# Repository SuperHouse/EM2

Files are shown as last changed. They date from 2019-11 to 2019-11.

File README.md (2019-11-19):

EtherMega2
==========
Copyright 2011-2018 Freetronics Pty Ltd www.freetronics.com.au  

The EtherMega2 is an Arduino-compatible board based on the existing
Arduino Mega2560, but with improvements and updates for features and
ease of use. It also includes on-board Ethernet with PoE (Power-over-
Ethernet) support.

Features:

 * High-efficiency switchmode power supply (input voltage 7-28Vdc)
 * Micro-USB Connector
 * microSD card slot
 * 10/100 Ethernet using the Wiznet W5500 chip
 * Overlay guide where you need it (both top and bottom)
 * D13 pin works for everything

You can learn more at:

  https://www.superhouse.tv/em2

INSTALLATION
------------
The design is saved as an EAGLE project. EAGLE PCB design software is
available from www.cadsoftusa.com free for non-commercial use. To use
this project download it and place the directory containing these files
into the "eagle" directory on your computer. Then open EAGLE and
navigate to the project.

DISTRIBUTION
------------
The specific terms of distribution of this project are governed by the
license referenced below.

LICENSE
-------
This work is licensed under the
Creative Commons Attribution-Share Alike License.  
To view a copy of this license, visit

  http://creativecommons.org/licenses/by-sa/3.0/  
  http://creativecommons.org/licenses/by-sa/3.0/legalcode

or send a letter to

  Creative Commons  
  171 Second Street, Suite 300  
  San Francisco  
  California, 94105  
  USA

The "license" folder within this repository also contains copies of the
licences referenced above.

CREDITS
-------
The EtherMega was designed by Jonathan Oxer (jon@freetronics.com) and
Marc Alexander (marc@freetronics.com) based on previous work by the Arduino
team (www.arduino.cc/playground/Main/People) which includes:

 * Massimo Banzi
 * David Cuartielles
 * Tom Igoe
 * Gianluca Martino
 * David A. Mellis

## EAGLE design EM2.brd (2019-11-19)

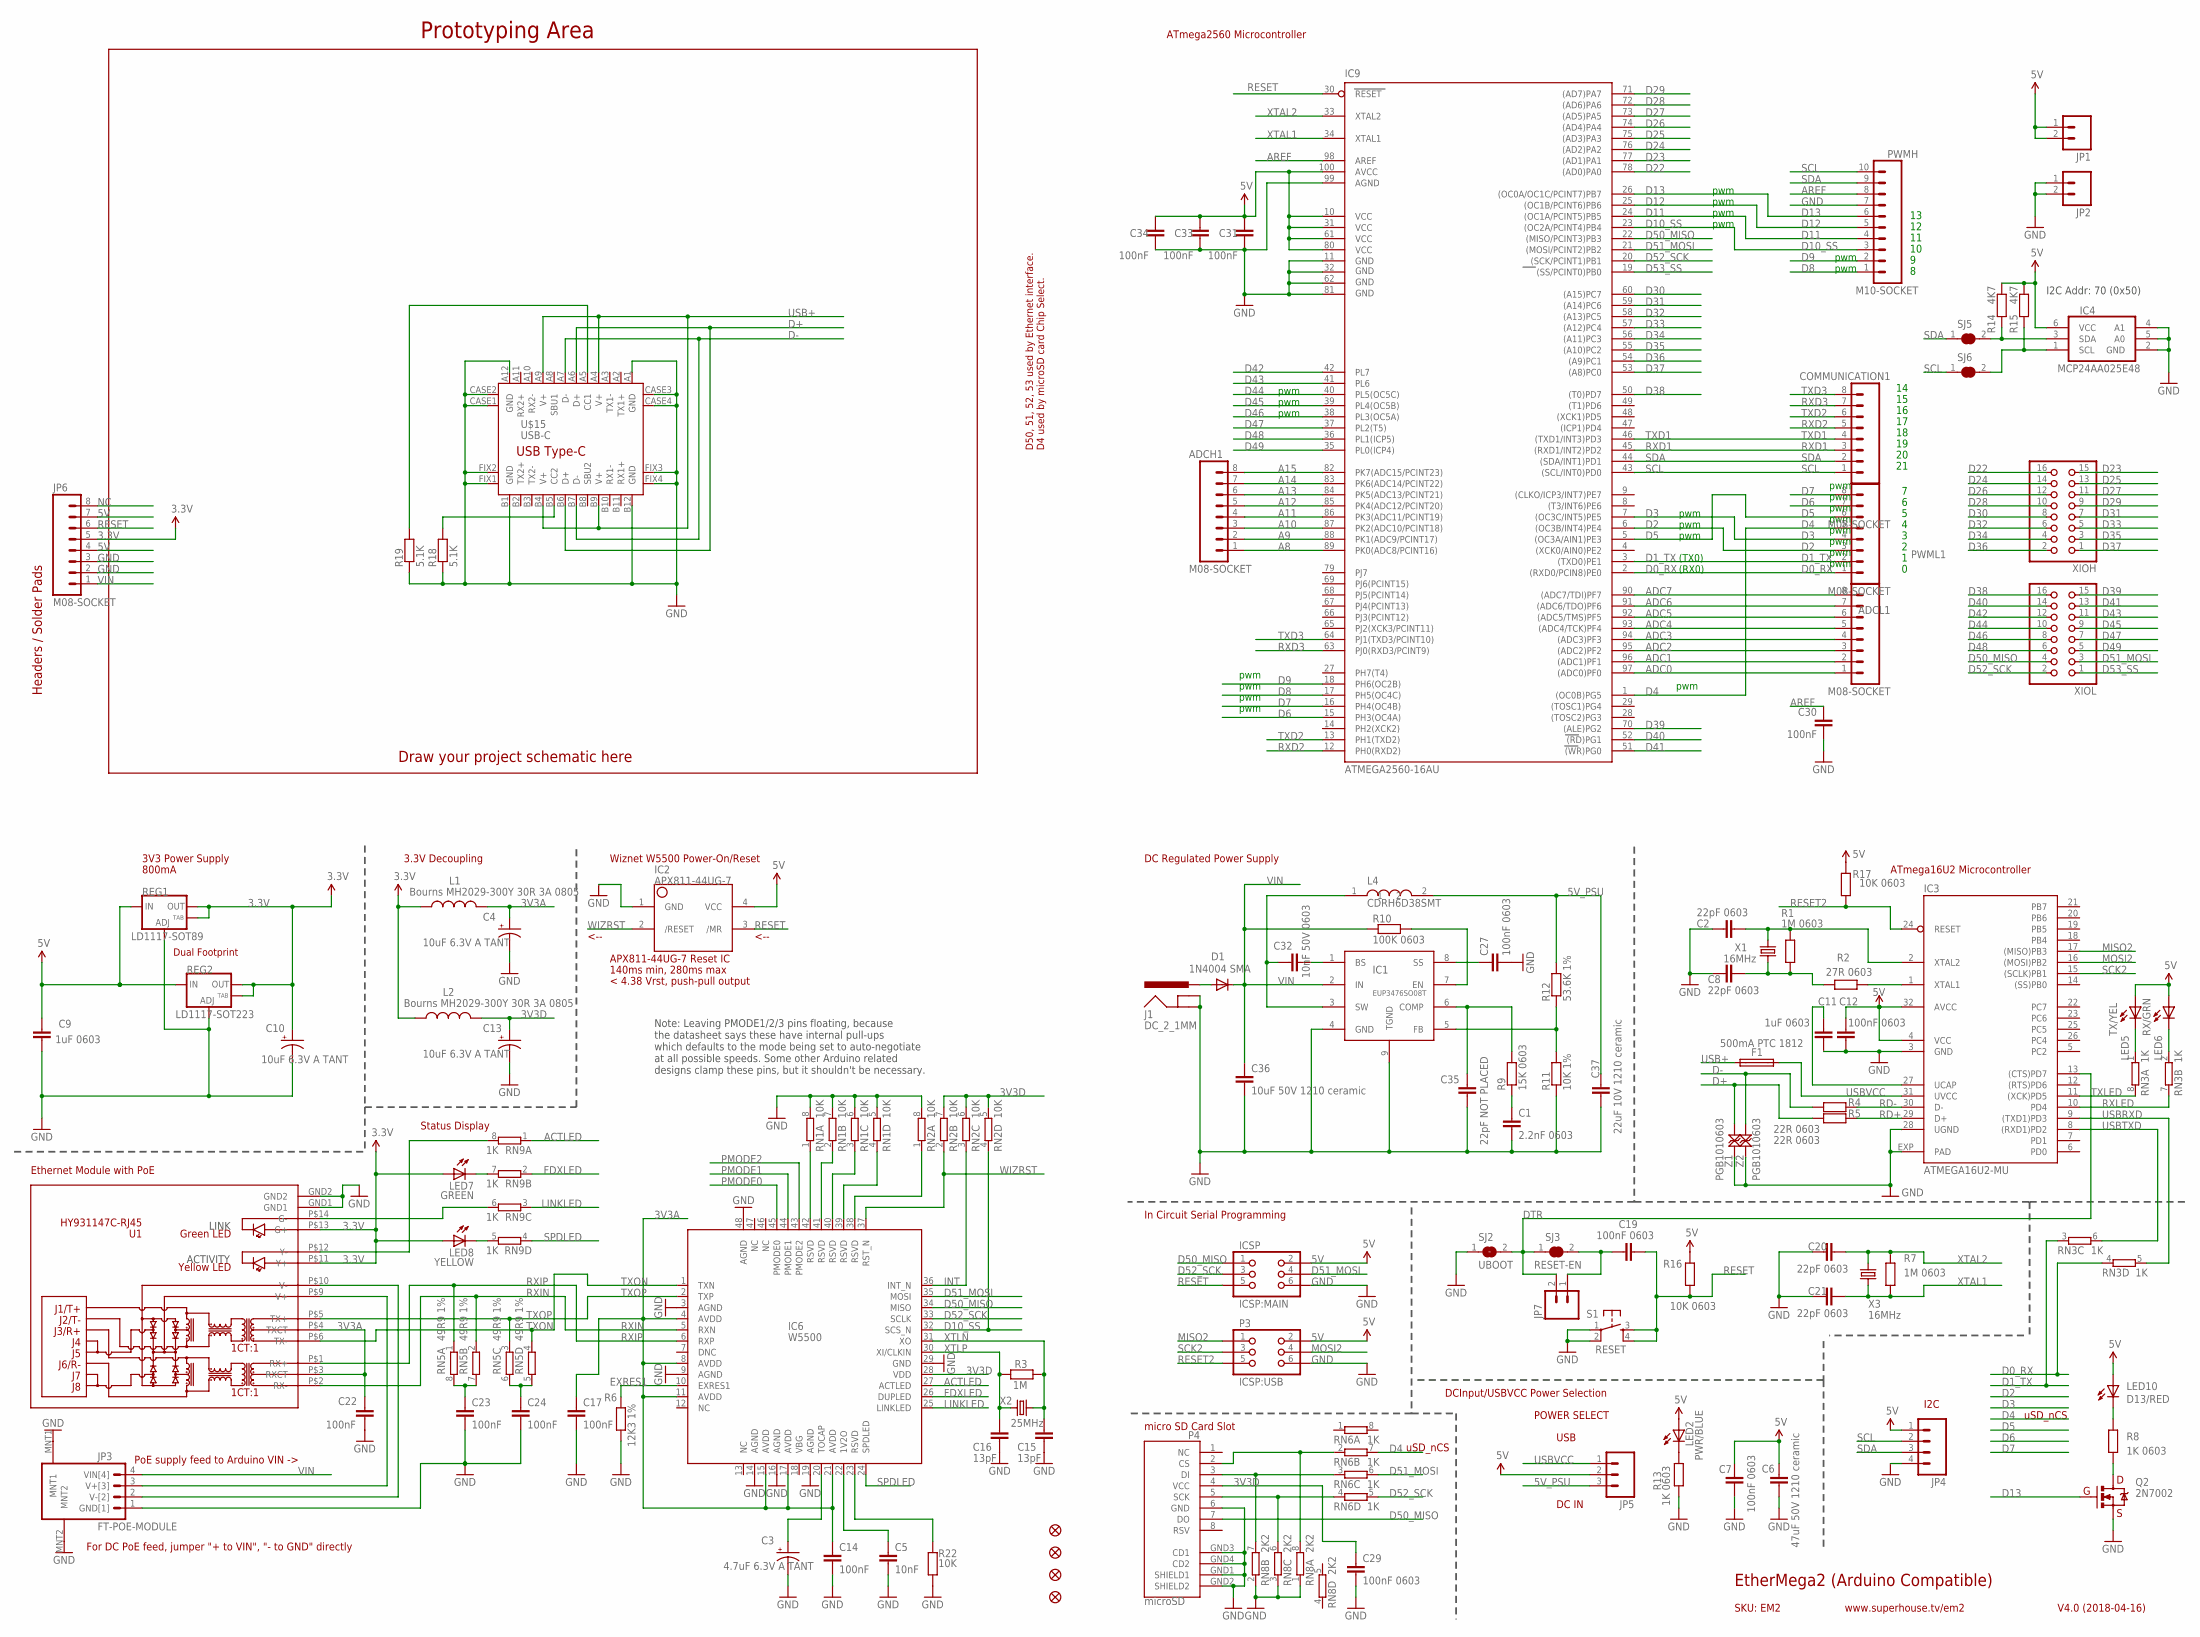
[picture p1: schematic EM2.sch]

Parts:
ADCH1: M08-SOCKET; 1X08-S
ADCL1: M08-SOCKET; 1X08-S
C1: 2.2nF 0603; C0603
C2, C8, C20, C21: 22pF 0603; C0603
C3: 4.7uF 6.3V A TANT; EIA3216
C4, C10, C13: 10uF 6.3V A TANT; EIA3216
C5: 10nF; C0603
C6: 47uF 50V 1210 ceramic; C1210
C7, C12, C19, C27, C29: 100nF 0603; C0603
C9, C11: 1uF 0603; C0603
C14, C17, C22, C23, C24, C30, C31, C33, C34: 100nF; C0603
C15, C16: 13pF; C0603
C32: 10nF 50V 0603; C0603
C35: 22pF NOT PLACED; C0603
C36: 10uF 50V 1210 ceramic; C1210
C37: 22uF 10V 1210 ceramic; C1210
COMMUNICATION1: M08-SOCKET; 1X08-S
D1: 1N4004 SMA; SMA-DIODE
F1: 500mA PTC 1812; 1812
FID1, FID2, FID3, FID4: FIDUCIAL1X2.5; FIDUCIAL-1X2.5
IC1: EUP3476SO08T; SO08T
IC2: APX811-44UG-7; SOT143-R
IC3: ATMEGA16U2-MU; ATMEL_QFN32
IC4: MCP24AA025E48; SOT23-6
IC6: W5500
IC9: ATMEGA2560-16AU; TQFP100
ICSP: ICSP:MAIN; 2X03-ICSP
J1: DC_2_1MM; POWER_JACK_SLOTS
JP1, JP2, JP7: M02PTH; 1X02
JP3: FT-POE-MODULE; FT-POE-MODULE-CLEAN
JP4: M04PTH; 1X04
JP5: M03-PIN; 1X03-P
JP6: M08-SOCKET; 1X08-S
L1, L2: Bourns MH2029-300Y 30R 3A 0805; L2012C
L4: CDRH6D38SMT; CDRH
LED2: PWR/BLUE; LED-0603
LED5: TX/YEL; LED-0603
LED6: RX/GRN; LED-0603
LED7: GREEN; LED-0603
LED8: YELLOW; LED-0603
LED10: D13/RED; LED-0603
P3: ICSP:USB; 2X03-ICSP
P4: microSD; MOLEX-SD-500901-003
PWMH: M10-SOCKET; 1X10-S
PWML1: M08-SOCKET; 1X08-S
Q2: 2N7002; SOT23-3
R1, R7: 1M 0603; R0603
R2: 27R 0603; R0603
R3: 1M; R0603
R4, R5: 22R 0603; R0603
R6: 12K3 1%; R0603
R8, R13: 1K 0603; R0603
R9: 15K 0603; R0603
R10: 100K 0603; R0603
R11: 10K 1%; R0603
R12: 53.6K 1%; R0603
R14, R15: 4K7; R0603
R16, R17: 10K 0603; R0603
R18, R19: 5.1K; R0603
R22: 10K; R0603
REG1: LD1117-SOT89; SOT89
REG2: LD1117-SOT223; SOT223
RN1, RN2: 10K; CAY16
RN3, RN6, RN9: 1K; CAY16
RN5: 49R9 1%; CAY16
RN8: 2K2; CAY16
S1: RESET; TACTILE_SMT-6MM
SJ2: UBOOT; SJ
SJ3: RESET-EN; SJC
SJ5, SJ6: SJCN; SJC
U1: HY931147C-RJ45; HY931147C
U$15: USB-C; USB-C-U52A
X1, X3: 16MHz; HC49U-V
X2: 25MHz; HC49U-V
XIOH: PINHD-2X8; 2X08
XIOL: PINHD-2X8; 2X08
Z1, Z2: PGB1010603; TVS0603

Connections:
3.3V: C10.A (+), JP6.5, L1.1, L2.1, LED7.A, LED8.A, REG1.2 (OUT), REG1.4 (OUT), REG2.2 (OUT), REG2.4 (OUT), U1.P$11 (Y+), U1.P$13 (G+)
3V3A: C4.A (+), C14.1, C17.1, C22.1, IC6.4 (AVDD), IC6.8 (AVDD), IC6.11 (AVDD), IC6.15 (AVDD), IC6.17 (AVDD), IC6.21 (AVDD), L1.2, U1.P$3 (RXCT), U1.P$4 (TXCT)
3V3D: C13.A (+), C29.1, IC6.28 (VDD), L2.2, P4.4 (VCC), RN2.5 (2), RN2.6 (2), RN2.7 (2)
5V: C6.2, C7.1, C9.1, C12.1, C31.1, C33.1, C34.1, IC2.4 (VCC), IC3.4 (VCC), IC3.32 (AVCC), IC4.6 (VCC), IC9.10 (VCC), IC9.31 (VCC1), IC9.61 (VCC2), IC9.80 (VCC3), IC9.100 (AVCC), ICSP.2, JP1.1, JP1.2, JP4.1, JP5.2, JP6.4, JP6.7, LED2.A, LED5.A, LED6.A, LED10.A, P3.2, R14.1, R15.1, R16.2, R17.2, REG1.3 (IN), REG2.3 (IN)
5V_PSU: C37.1, JP5.3, L4.2, R12.2
A8: ADCH1.1, IC9.89 (PK0(ADC8/PCINT16))
A9: ADCH1.2, IC9.88 (PK1(ADC9/PCINT17))
A10: ADCH1.3, IC9.87 (PK2(ADC10/PCINT18))
A11: ADCH1.4, IC9.86 (PK3(ADC11/PCINT19))
A12: ADCH1.5, IC9.85 (PK4(ADC12/PCINT20))
A13: ADCH1.6, IC9.84 (PK5(ADC13/PCINT21))
A14: ADCH1.7, IC9.83 (PK6(ADC14/PCINT22))
A15: ADCH1.8, IC9.82 (PK7(ADC15/PCINT23))
ACTLED: IC6.27 (ACTLED), RN9.1
ADC0: ADCL1.1, IC9.97 ((ADC0)PF0)
ADC1: ADCL1.2, IC9.96 ((ADC1)PF1)
ADC2: ADCL1.3, IC9.95 ((ADC2)PF2)
ADC3: ADCL1.4, IC9.94 ((ADC3)PF3)
ADC4: ADCL1.5, IC9.93 ((ADC4/TCK)PF4)
ADC5: ADCL1.6, IC9.92 ((ADC5/TMS)PF5)
ADC6: ADCL1.7, IC9.91 ((ADC6/TDO)PF6)
ADC7: ADCL1.8, IC9.90 ((ADC7/TDI)PF7)
AREF: C30.1, IC9.98 (AREF), PWMH.8
D0_RX: IC9.2 ((RXD0/PCIN8)PE0), PWML1.1, RN3.4 (1)
D1_TX: IC9.3 ((TXD0)PE1), PWML1.2, RN3.3 (1)
D2: IC9.6 ((OC3B/INT4)PE4), PWML1.3
D3: IC9.7 ((OC3C/INT5)PE5), PWML1.4
D4: IC9.1 ((OC0B)PG5), PWML1.5, RN6.7 (2)
D5: IC9.5 ((OC3A/AIN1)PE3), PWML1.6
D6: IC9.15 (PH3(OC4A)), PWML1.7
D7: IC9.16 (PH4(OC4B)), PWML1.8
D8: IC9.17 (PH5(OC4C)), PWMH.1
D9: IC9.18 (PH6(OC2B)), PWMH.2
D10_SS: IC6.32 (SCS_N), IC9.23 ((OC2A/PCINT4)PB4), PWMH.3, RN2.4 (1)
D11: IC9.24 ((OC1A/PCINT5)PB5), PWMH.4
D12: IC9.25 ((OC1B/PCINT6)PB6), PWMH.5
D13: IC9.26 ((OC0A/OC1C/PCINT7)PB7), PWMH.6, Q2.1 (G)
D22: IC9.78 ((AD0)PA0), XIOH.16
D23: IC9.77 ((AD1)PA1), XIOH.15
D24: IC9.76 ((AD2)PA2), XIOH.14
D25: IC9.75 ((AD3)PA3), XIOH.13
D26: IC9.74 ((AD4)PA4), XIOH.12
D27: IC9.73 ((AD5)PA5), XIOH.11
D28: IC9.72 ((AD6)PA6), XIOH.10
D29: IC9.71 ((AD7)PA7), XIOH.9
D30: IC9.60 ((A15)PC7), XIOH.8
D31: IC9.59 ((A14)PC6), XIOH.7
D32: IC9.58 ((A13)PC5), XIOH.6
D33: IC9.57 ((A12)PC4), XIOH.5
D34: IC9.56 ((A11)PC3), XIOH.4
D35: IC9.55 ((A10)PC2), XIOH.3
D36: IC9.54 ((A9)PC1), XIOH.2
D37: IC9.53 ((A8)PC0), XIOH.1
D38: IC9.50 ((T0)PD7), XIOL.16
D39: IC9.70 ((ALE)PG2), XIOL.15
D40: IC9.52 ((RD)PG1), XIOL.14
D41: IC9.51 ((WR)PG0), XIOL.13
D42: IC9.42 (PL7), XIOL.12
D43: IC9.41 (PL6), XIOL.11
D44: IC9.40 (PL5(OC5C)), XIOL.10
D45: IC9.39 (PL4(OC5B)), XIOL.9
D46: IC9.38 (PL3(OC5A)), XIOL.8
D47: IC9.37 (PL2(T5)), XIOL.7
D48: IC9.36 (PL1(ICP5)), XIOL.6
D49: IC9.35 (PL0(ICP4)), XIOL.5
D50_MISO: IC6.34 (MISO), IC9.22 ((MISO/PCINT3)PB3), ICSP.1, P4.7 (DO), XIOL.4
D51_MOSI: IC6.35 (MOSI), IC9.21 ((MOSI/PCINT2)PB2), ICSP.4, RN6.6 (2), XIOL.3
D52_SCK: IC6.33 (SCLK), IC9.20 ((SCK/PCINT1)PB1), ICSP.3, RN6.5 (2), XIOL.2
D53_SS: IC9.19 ((SS/PCINT0)PB0), XIOL.1
D+: R5.2, U$15.A6 (D+), U$15.B6 (D+), Z1.1
D-: R4.2, U$15.A7 (D-), U$15.B7 (D-), Z2.1
DTR: IC3.13 ((CTS)PD7), JP7.2, SJ2.2, SJ3.1
EXRES1: IC6.10 (EXRES1), R6.2
FDXLED: IC6.26 (DUPLED), RN9.2 (1)
GND: C1.2, C2.1, C3.C (-), C4.C (-), C5.2, C6.1, C7.2, C8.1, C9.2, C10.C (-), C11.2, C12.2, C13.C (-), C14.2, C15.2, C16.2, C17.2, C20.1, C21.1, C22.2, C23.2, C24.2, C27.2, C29.2, C30.2, C31.2, C33.2, C34.2, C35.2, C36.2, C37.2, IC1.4 (GND), IC1.9 (TGND), IC2.1 (GND), IC3.3 (GND), IC3.28 (UGND), IC3.EXP (PAD), IC4.2 (GND), IC4.4 (A1), IC4.5 (A0), IC6.3 (AGND), IC6.9 (AGND), IC6.14 (AGND), IC6.16 (AGND), IC6.19 (AGND), IC6.29 (GND), IC6.48 (AGND), IC9.11 (GND), IC9.32 (GND1), IC9.62 (GND2), IC9.81 (GND3), IC9.99 (AGND), ICSP.6, J1.GND, J1.GNDBREAK, JP2.1, JP2.2, JP3.1 (GND[1]), JP3.MNT1, JP3.MNT2, JP4.4, JP6.2, JP6.3, P3.6, P4.6 (GND), P4.GND1 (SHIELD1), P4.GND2 (SHIELD2), P4.GND3 (CD1), P4.GND4 (CD2), PWMH.7, Q2.2 (S), R6.1, R11.1, R13.1, R18.1, R19.1, R22.1, REG1.1 (ADJ), REG2.1 (ADJ), RN1.5 (2), RN1.6 (2), RN1.7 (2), RN1.8 (2), RN2.8 (2), RN8.1, RN8.2 (1), RN8.3 (1), S1.1, S1.2, SJ2.1, U1.GND1, U1.GND2, U$15.A1 (GND), U$15.A12 (GND), U$15.B1 (GND), U$15.B12 (GND), U$15.CASE1 (GND), U$15.CASE2 (GND), U$15.CASE3 (GND), U$15.CASE4 (GND), U$15.FIX1 (GND), U$15.FIX2 (GND), U$15.FIX3 (GND), U$15.FIX4 (GND), Z1.2, Z2.2
INT: IC6.36 (INT_N), RN2.3 (1)
LINKLED: IC6.25 (LINKLED), RN9.3 (1)
MISO2: IC3.17 ((MISO)PB3), P3.1
MOSI2: IC3.16 ((MOSI)PB2), P3.4
unnamed: C24.1, RN5.5 (2), RN5.6 (2)
unnamed: LED10.C, R8.2
unnamed: Q2.3 (D), R8.1
unnamed: IC3.1 (XTAL1), R2.1
unnamed: IC4.1 (SCL), R15.2, SJ6.2
unnamed: LED6.C, RN3.2 (1)
unnamed: LED2.C, R13.2
unnamed: LED5.C, RN3.1
unnamed: R18.2, U$15.B5 (CC2)
unnamed: IC4.3 (SDA), R14.2, SJ5.2
unnamed: P4.5 (SCK), RN6.4 (1), RN8.6 (2)
unnamed: P4.2 (CS), RN6.2 (1), RN8.8 (2)
unnamed: P4.3 (DI), RN6.3 (1), RN8.7 (2)
unnamed: LED8.C, RN9.5 (2)
unnamed: RN9.6 (2), U1.P$14 (G-)
unnamed: D1.A, J1.PWR
unnamed: IC6.39 (RSVD), RN1.4 (1)
unnamed: IC6.40 (RSVD), RN1.3 (1)
unnamed: C27.1, IC1.8 (SS)
unnamed: C1.1, R9.1
unnamed: C35.1, IC1.6 (COMP), R9.2
unnamed: R19.2, U$15.A5 (CC1)
unnamed: JP3.3 (V+[3]), U1.P$9 (V+)
unnamed: JP3.2 (V-[2]), U1.P$10 (V-)
unnamed: C32.1, IC1.3 (SW), L4.1
unnamed: C32.2, IC1.1 (BS)
unnamed: IC1.7 (EN), R10.2
unnamed: IC6.41 (RSVD), RN1.2 (1)
unnamed: C19.1, JP7.1, SJ3.2
unnamed: IC6.42 (RSVD), RN1.1
unnamed: IC1.5 (FB), R11.2, R12.1
unnamed: IC6.23 (RSVD), R22.2
unnamed: IC6.38 (RSVD), RN2.1
unnamed: C5.1, IC6.22 (1V2O)
unnamed: C3.A (+), IC6.20 (TOCAP)
unnamed: C2.2, IC3.2 (XTAL2), R1.2, X1.2
unnamed: C8.2, R1.1, R2.2, X1.1
unnamed: C11.1, IC3.27 (UCAP)
unnamed: C23.1, RN5.7 (2), RN5.8 (2)
unnamed: LED7.C, RN9.7 (2)
unnamed: RN9.8 (2), U1.P$12 (Y-)
NC: JP6.8
PMODE0: IC6.45 (PMODE0)
PMODE1: IC6.44 (PMODE1)
PMODE2: IC6.43 (PMODE2)
RD+: IC3.29 (D+), R5.1
RD-: IC3.30 (D-), R4.1
RESET: C19.2, IC2.3 (/MR), IC9.30 (RESET), ICSP.5, JP6.6, R16.1, S1.3, S1.4
RESET2: IC3.24 (RESET), P3.5, R17.1
RXD1: COMMUNICATION1.3, IC9.45 ((RXD1/INT2)PD2)
RXD2: COMMUNICATION1.5, IC9.12 (PH0(RXD2))
RXD3: COMMUNICATION1.7, IC9.63 (PJ0(RXD3/PCINT9))
RXIN: IC6.5 (RXN), RN5.2 (1), U1.P$2 (RX-)
RXIP: IC6.6 (RXP), RN5.1, U1.P$1 (RX+)
RXLED: IC3.10 (PD4), RN3.7 (2)
SCK2: IC3.15 ((SCLK)PB1), P3.3
SCL: COMMUNICATION1.1, IC9.43 ((SCL/INT0)PD0), JP4.2, PWMH.10, SJ6.1
SDA: COMMUNICATION1.2, IC9.44 ((SDA/INT1)PD1), JP4.3, PWMH.9, SJ5.1
SPDLED: IC6.24 (SPDLED), RN9.4 (1)
TXD1: COMMUNICATION1.4, IC9.46 ((TXD1/INT3)PD3)
TXD2: COMMUNICATION1.6, IC9.13 (PH1(TXD2))
TXD3: COMMUNICATION1.8, IC9.64 (PJ1(TXD3/PCINT10))
TXLED: IC3.11 ((XCK)PD5), RN3.8 (2)
TXON: IC6.1 (TXN), RN5.4 (1), U1.P$6 (TX-)
TXOP: IC6.2 (TXP), RN5.3 (1), U1.P$5 (TX+)
USB+: F1.1, U$15.A4 (V+), U$15.A9 (V+), U$15.B4 (V+), U$15.B9 (V+)
USBRXD: IC3.9 ((TXD1)PD3), RN3.5 (2)
USBTXD: IC3.8 ((RXD1)PD2), RN3.6 (2)
USBVCC: F1.2, IC3.31 (UVCC), JP5.1
VIN: C36.1, D1.C, IC1.2 (IN), JP3.4 (VIN[4]), JP6.1, R10.1
WIZRST: IC2.2 (/RESET), IC6.37 (RST_N), RN2.2 (1)
XTAL1: C21.2, IC9.34 (XTAL1), R7.1, X3.1
XTAL2: C20.2, IC9.33 (XTAL2), R7.2, X3.2
XTLN: C15.1, IC6.31 (XO), R3.1, X2.1
XTLP: C16.1, IC6.30 (XI/CLKIN), R3.2, X2.2

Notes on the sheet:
Prototyping Area
3V3 Power Supply
Status Display
Headers / Solder Pads
Dual Footprint
3.3V Decoupling
Draw your project schematic here
D50, 51, 52, 53 used by Ethernet interface.
PoE supply feed to Arduino VIN ->
For DC PoE feed, jumper "+ to VIN", "- to GND" directly
DC Regulated Power Supply
ATmega2560 Microcontroller
APX811-44UG-7 Reset IC
140ms min, 280ms max
ATmega16U2 Microcontroller
DCInput/USBVCC Power Selection
Wiznet W5500 Power-On/Reset
uSD_nCS
800mA
In Circuit Serial Programming
micro SD Card Slot
EtherMega2 (Arduino Compatible)
V4.0 (2018-04-16)
www.superhouse.tv/em2
SKU: EM2
Ethernet Module with PoE
< 4.38 Vrst, push-pull output
<--
D4 used by microSD card Chip Select.
pwm
(TX0)
(RX0)
I2C
USB
DC IN
POWER SELECT
I2C Addr: 70 (0x50)
LINK
ACTIVITY
Note: Leaving PMODE1/2/3 pins floating, because the datasheet says these have internal pull-ups which defaults to the mode being set to auto-negotiate at all possible speeds. Some other Arduino related designs clamp these pins, but it shouldn't be necessary.

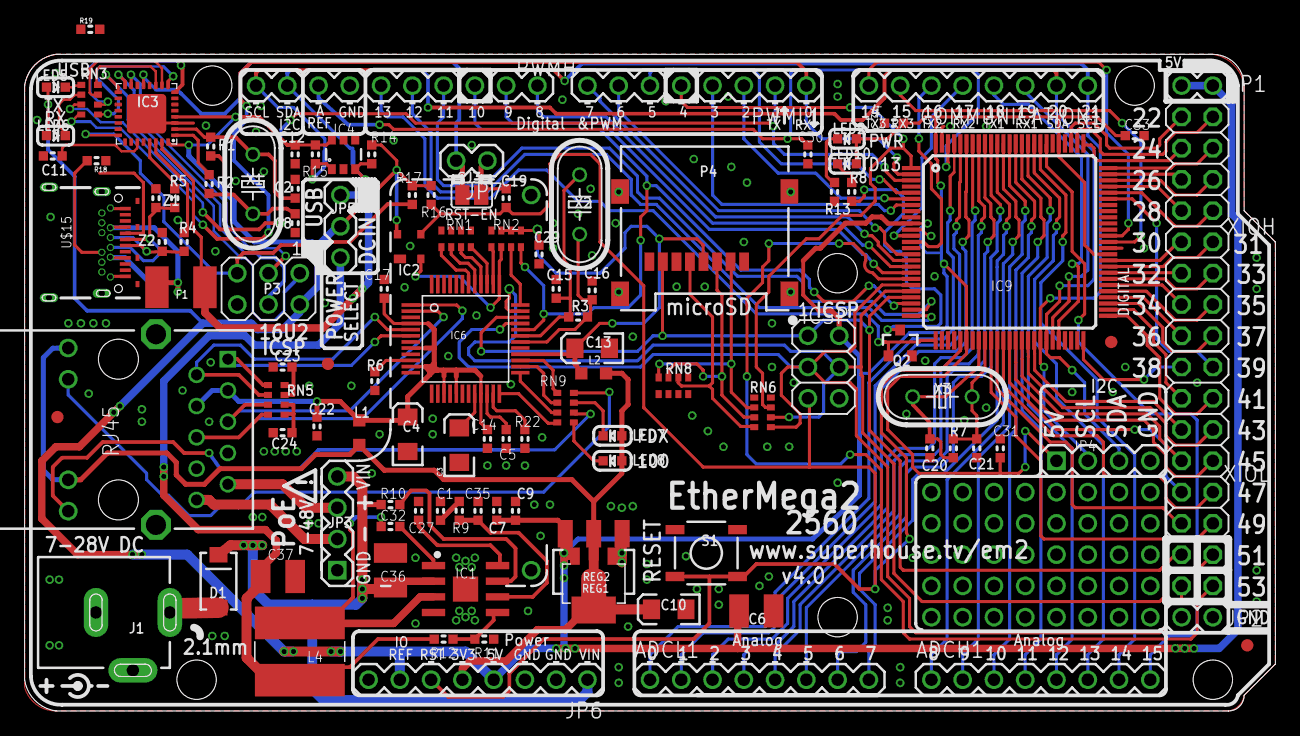
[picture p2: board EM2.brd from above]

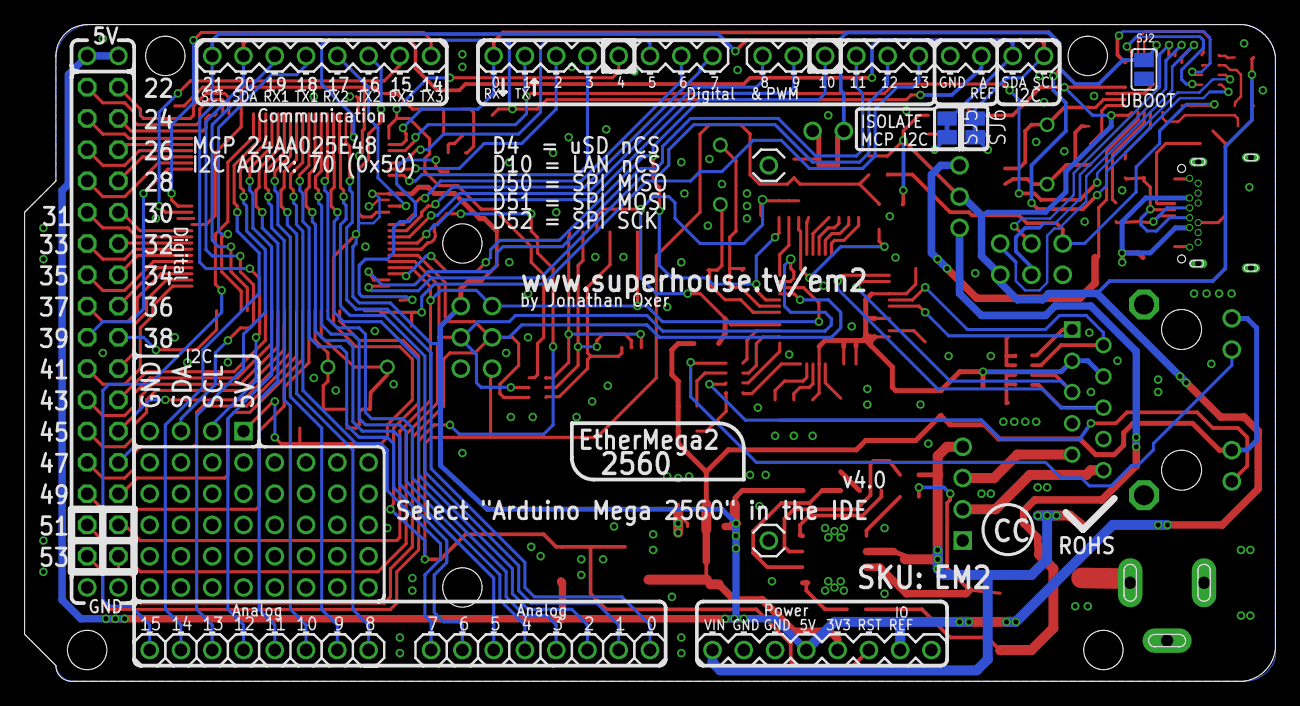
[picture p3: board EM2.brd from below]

Board: 2 copper layers, 101.6 x 53.3 mm, 114 parts (3 on the bottom side), 150 nets.

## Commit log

2018-04-11 Renamed project for major update to W5500
    [EM2.brd, EM2.sch]
2018-04-16 Major rework using W5500 ethernet chip
    [EM2.brd, EM2.sch]
2018-05-16 Finished conversion to W5500 and all DRC for release
    [EM2.brd, EM2.sch]
2019-04-23 Changed USB socket
    [EM2.brd, EM2.sch]
2019-11-19 Library part migration to SuperHouse
    [EM2.brd, EM2.sch]
